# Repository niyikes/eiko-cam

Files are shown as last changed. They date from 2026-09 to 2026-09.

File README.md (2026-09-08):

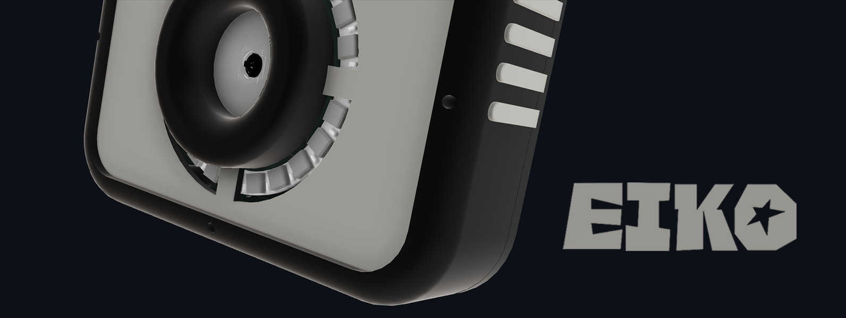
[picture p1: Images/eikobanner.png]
Eiko banner


> *a camera built with the Orange Pi CM4, with rotary encoders, a TFT screen and 24-LED RGB ring.*

---
## What is this?

Eiko is a handheld camera built from scratch, with the Orange Pi CM4.

It takes photos, has a TFT screen and a 24-LED RGB ring around the lens that you can change colors with a rotary encoder.
| | |
|---|---|
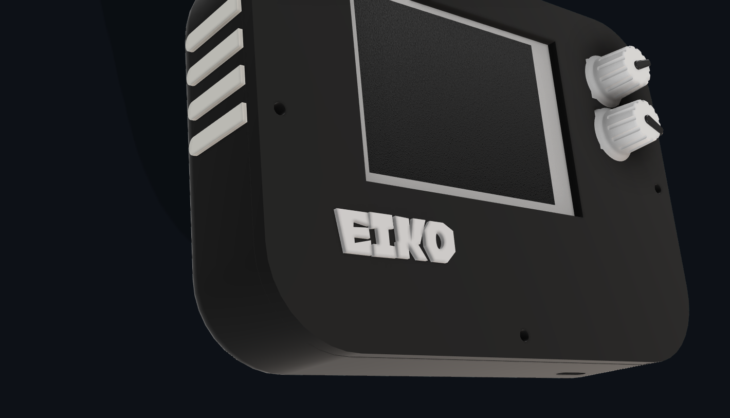
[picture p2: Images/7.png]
Images
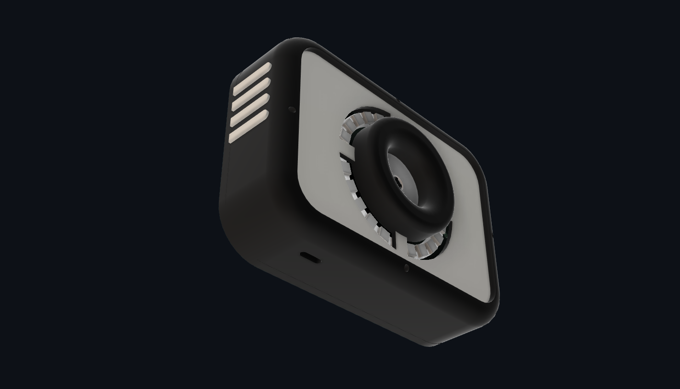
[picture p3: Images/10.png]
Images
||

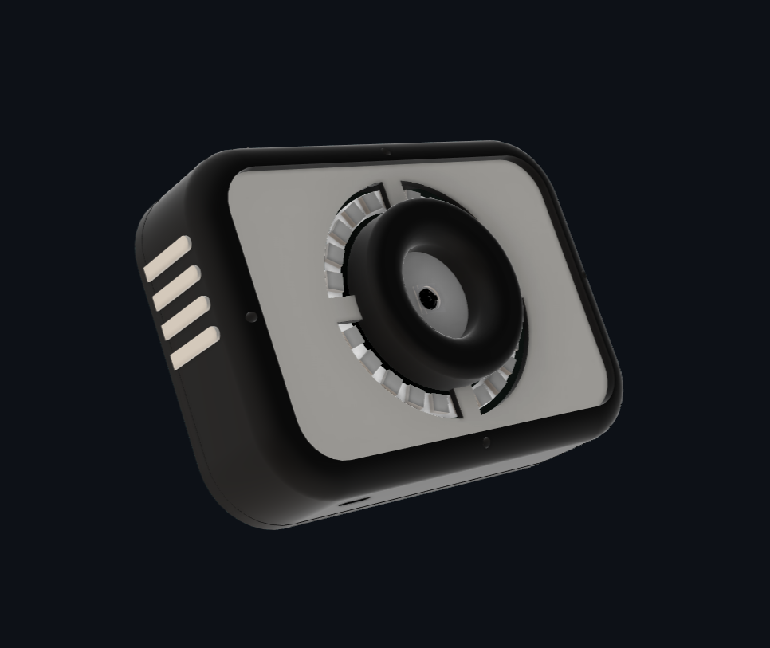
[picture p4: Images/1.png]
case


## features

- live preview on a 2.8" TFT
- full res JPEG capture (using an 8MP IMX219 camera)
- rgb led ring for colorful lighting & flash
- two rotary encoders (one shoots, one controls the leds)
- saves to SD card

## PCB

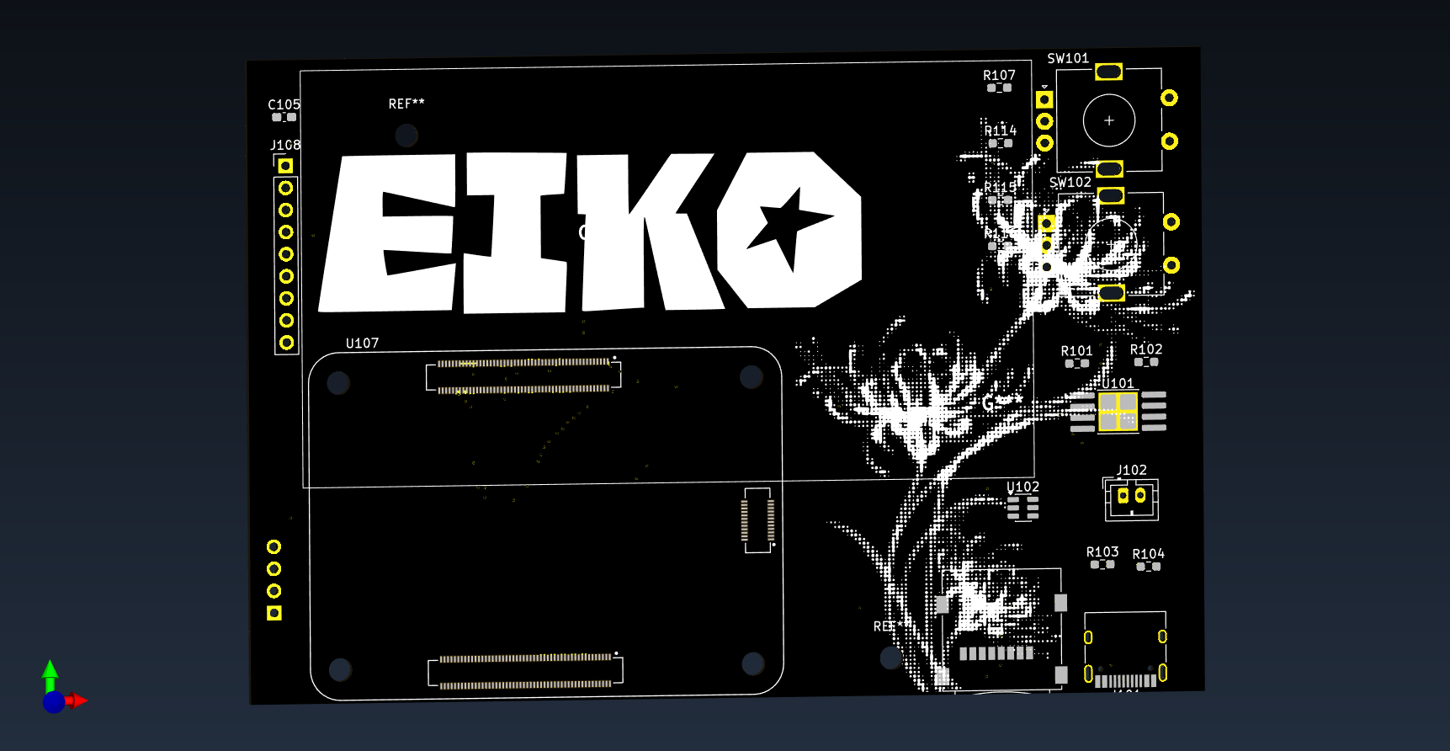
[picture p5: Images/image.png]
front

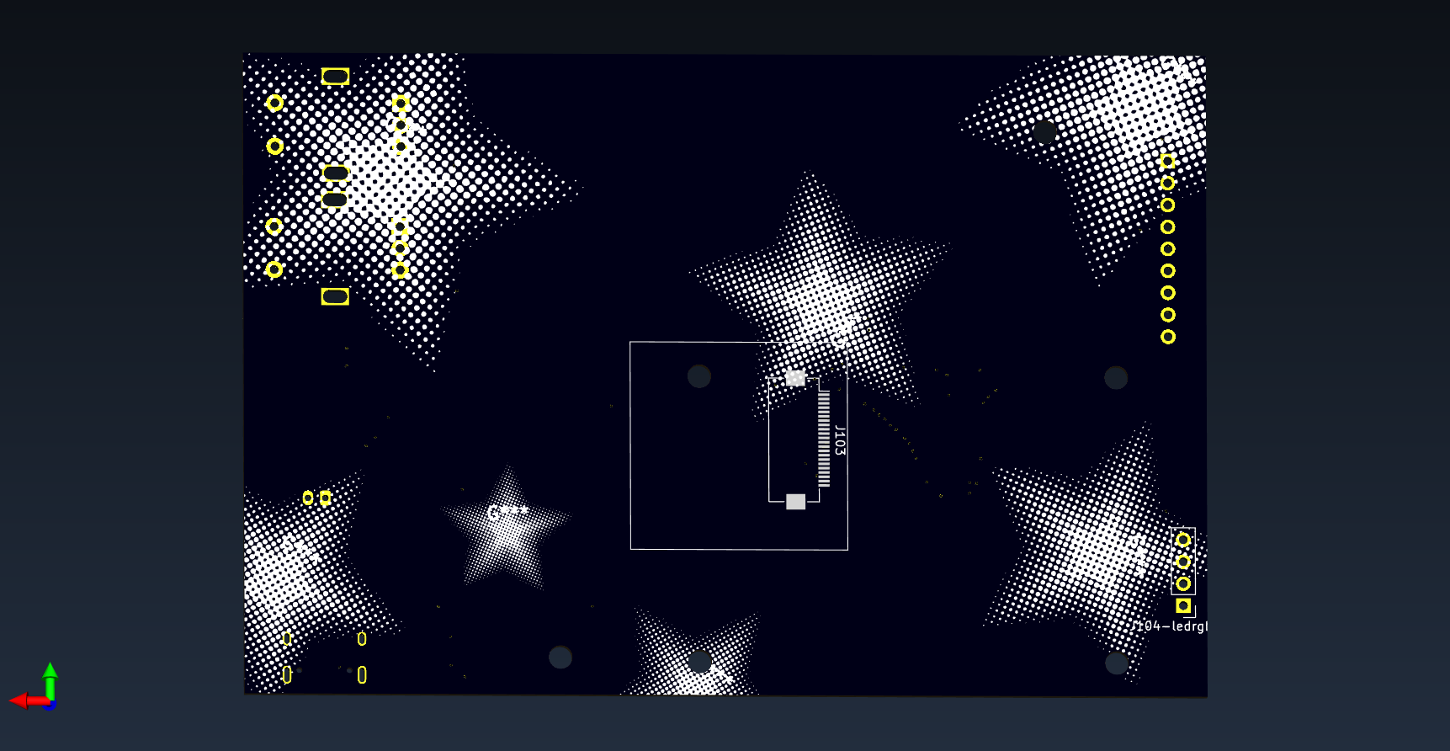
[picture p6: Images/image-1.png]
back


## Cad

| Case Front | Case Back | Plate |
|---|---|---|
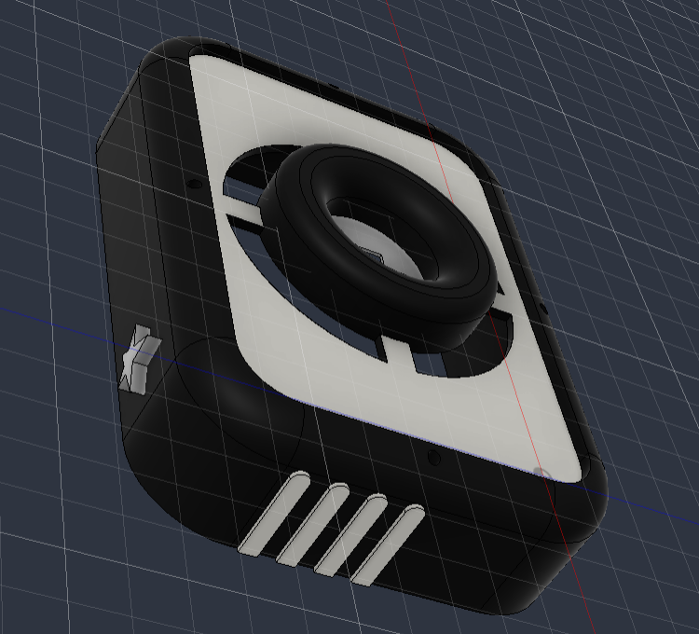
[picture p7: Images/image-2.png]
case front
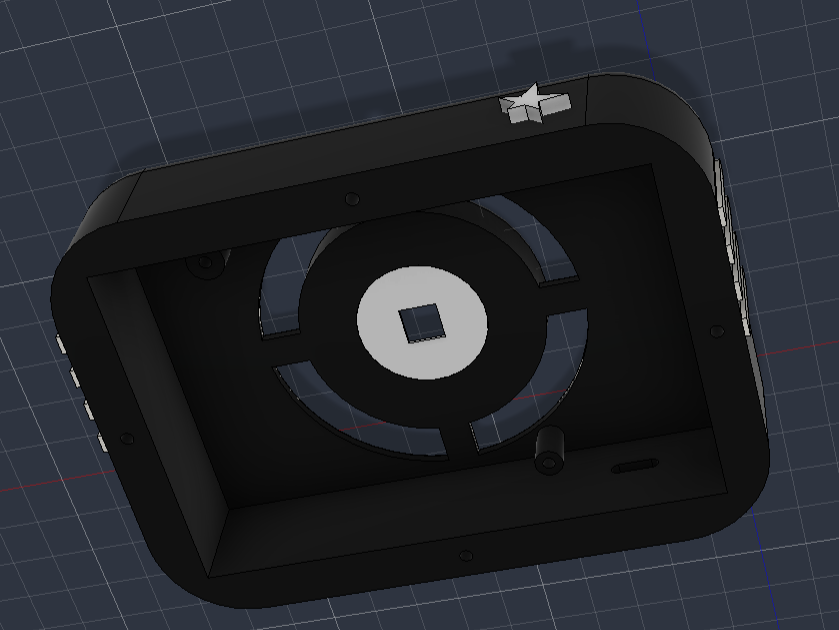
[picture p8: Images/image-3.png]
case back
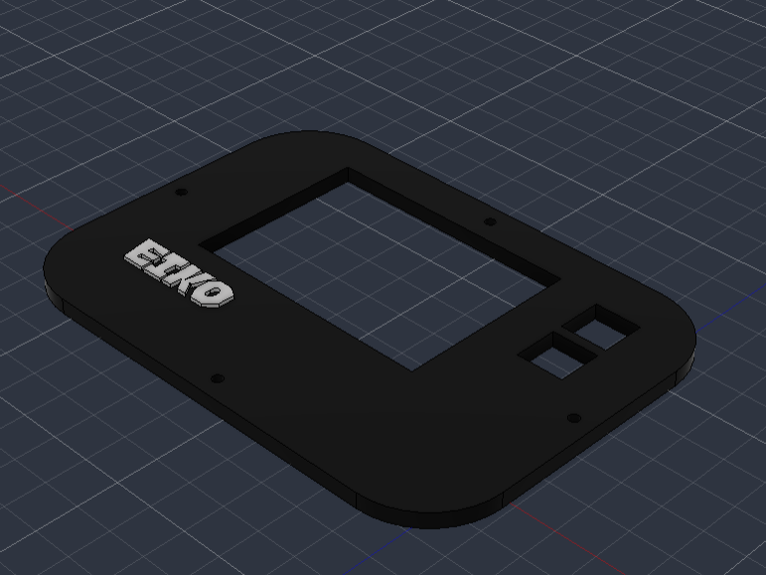
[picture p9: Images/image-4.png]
plate
| | | |

## Firmware
You can find the firmware [here](https://github.com/niyikes/eiko-cam/tree/main/firmware)
| Input | Action |
|---|---|
| Rotate enc1 | Navigate menu |
| Press enc1 | Shutter/Click picture |
| Press enc2 | Toggle LED ring on/off |
| Rotate enc2 | Change LED color |

### Flash the firmware
Connect the Orange Pi CM4 and run:

```
./setup.sh
sudo python3 eiko.py
```

## BOM
| Component | Qty | Price (INR) | Total (INR) | Total (USD) | Source |
|---|-----|---|---|---|---|
| Orange Pi CM4 | 1 | 6095 | 6095 | 64.50 | [crazypi.com](https://www.crazypi.com/Orange-Pi-Compute-Module-4) |
| TP4056 LiPo Charger | 1 | 184 | 184 | 1.95 | [robu.in](https://robu.in/product/tp4056-3-7v-lithium-battery-charging-module-1a-usb-type-c-port-ph2-0-terminal/) |
| USB-C Receptacle | 1 | 280 | 280 | 2.96 | [robu.in](https://robu.in/product/usb4745-03-a-gct-usb-sealed-connector-top-mount-usb-type-c-usb-3-2-receptacle-24-position/) |
| MT3608 Boost Converter | 1 | 20 | 20 | 0.21 | [robu.in](https://robu.in/product/mt3608-xian-aerosemi-tech-boost-type-adjustable-2a-2v24v-sot-23-6-dc-dc-converters-rohs/) |
| MicroSD Storage Board | 1 | 389 | 389 | 4.12 | [robu.in](https://robu.in/product/waveshare-micro-sdtf-storage-board/) |
| Alps EC11E Rotary Encoder | 2 | 415.24 | 830.48 | 8.79 | [element14.com](https://in.element14.com/alps/ec11e15204a3/encoder-vertical-30-det-15ppr/dp/1520804) |
| IMX219 Camera | 1 | 3659 | 3659 | 38.72 | [robu.in](https://robu.in/product/arducam-8mp-imx219-camera-module-with-fisheye-lens-for-jeson-nano-and-raspberry-pi-compute-module/) |
| WS2812 24-LED Ring | 1 | 131 | 131 | 1.39 | [robu.in](https://robu.in/product/24-bit-ws2812-5050-rgb-led-built-full-color-driving-lights-circular-development-board/) |
| 2.8" SPI TFT | 1 | 869 | 869 | 9.20 | [robu.in](https://robu.in/product/2-8-inch-spi-touch-screen-module-tft-interface-240320/) |
| 100nF Cap | 1 | 4.64 | 4.64 | 0.05 | [robu.in](https://robu.in/product/100nf-400v-dip-polyester-film-capacitor-pitch10mm/) |
| 1.2k Resistor | 2 | 1.18 | 2.36 | 0.02 | [sharvielectronics.com](https://sharvielectronics.com/product/1-2k-ohm-1-2-watt-resistor-5-tolerance/) |
| 10k Resistor | 5 | 0.45 | 2.25 | 0.02 | [sharvielectronics.com](https://sharvielectronics.com/product/10k-ohm-1-4-watt-resistor-5-tolerance/) |
| 100k Resistor | 2 | 0.45 | 0.90 | 0.01 | [sharvielectronics.com](https://sharvielectronics.com/product/100k-ohm-1-4-watt-resistor-5-tolerance/) |
| 13k Resistor | 2 | 1.08 | 2.16 | 0.02 | [robu.in](https://robu.in/product/mf25-13k-multicomp-pro-through-hole-resistor-13-kohm-mf25-series-250-mw/) |
| LiPo Battery | 1 | 329 | 329 | 3.48 | [robu.in](https://robu.in/product/nova-103450-2000mah-3-7v-lipo-battery-pack/) |
| M2.5 Screws | 10 | 1.24 | 12.40 | 0.13 | [onlyscrews.in](https://onlyscrews.in/products/m2-5-x-6mm-phillips-pan-head-ss-304-screw) |
| Heat Set Inserts | 10 | 2.50 | 25.00 | 0.26 | [flyrobo.in](https://www.flyrobo.in/m2.5-x-5mm-brass-heat-set-threaded-round-insert-nut) |
| **TOTAL** | | | | **$135.45** | |

I loved making this project, it was super fun and i learnt a LOT in the process. SUPER HAPPY WITH HOW IT TURNED OUT! :D

<br><br>
-ˋˏ✄┈┈┈┈
made with <3 by nia

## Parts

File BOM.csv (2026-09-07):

Name | Qty | Price (INR) | Total (INR) | Total (USD) | Source
Orange Pi CM4 | 1 | 6095 | 6095 | 64.50 | https://www.crazypi.com/Orange-Pi-Compute-Module-4
TP4056 3.7V LiPo Charger | 1 | 184 | 184 | 1.95 | https://robu.in/product/tp4056-3-7v-lithium-battery-charging-module-1a-usb-type-c-port-ph2-0-terminal/
USB-C receptacle | 1 | 280 | 280 | 2.96 | https://robu.in/product/usb4745-03-a-gct-usb-sealed-connector-top-mount-usb-type-c-usb-3-2-receptacle-24-position/
MT3608 boost converter | 1 | 20 | 20 | 0.21 | https://robu.in/product/mt3608-xian-aerosemi-tech-boost-type-adjustable-2a-2v24v-sot-23-6-dc-dc-converters-rohs/
Micro SD(TF) Storage Board | 1 | 389 | 389 | 4.12 | https://robu.in/product/waveshare-micro-sdtf-storage-board/
Alps EC11E Rotary Encoder | 2 | 415.24 | 830.48 | 8.79 | https://in.element14.com/alps/ec11e15204a3/encoder-vertical-30-det-15ppr/dp/1520804
IMX219 camera | 1 | 3659 | 3659 | 38.72 | https://robu.in/product/arducam-8mp-imx219-camera-module-with-fisheye-lens-for-jeson-nano-and-raspberry-pi-compute-module/
LED Ring | 1 | 131 | 131 | 1.39 | https://robu.in/product/24-bit-ws2812-5050-rgb-led-built-full-color-driving-lights-circular-development-board/
SPI TFT 2.8" | 1 | 869 | 869 | 9.20 | https://robu.in/product/2-8-inch-spi-touch-screen-module-tft-interface-240320/
100nF Cap | 1 | 4.64 | 4.64 | 0.05 | https://robu.in/product/100nf-400v-dip-polyester-film-capacitor-pitch10mm/
1.2k Resistor | 2 | 1.18 | 2.36 | 0.02 | https://sharvielectronics.com/product/1-2k-ohm-1-2-watt-resistor-5-tolerance/
10k resistor | 5 | 0.45 | 2.25 | 0.02 | https://sharvielectronics.com/product/10k-ohm-1-4-watt-resistor-5-tolerance/
100k resistor | 2 | 0.45 | 0.9 | 0.01 | https://sharvielectronics.com/product/100k-ohm-1-4-watt-resistor-5-tolerance/
13k resistor | 2 | 1.08 | 2.16 | 0.02 | https://robu.in/product/mf25-13k-multicomp-pro-through-hole-resistor-13-kohm-mf25-series-250-mw-%25c2%25b1-1-axial-leaded-250-v/
LiPo battery | 1 | 329 | 329 | 3.48 | https://robu.in/product/nova-103450-2000mah-3-7v-lipo-battery-pack/
M2.5 screws | 10 | 1.24 | 12.4 | 0.13 | https://onlyscrews.in/products/m2-5-x-6mm-phillips-pan-head-ss-304-screw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
Heat set inserts | 10 | 2.5 | 25 | 0.26 | https://www.flyrobo.in/m2.5-x-5mm-brass-heat-set-threaded-round-insert-nut?tracking=ads
 |  |  | TOTAL (USD): | 135.45

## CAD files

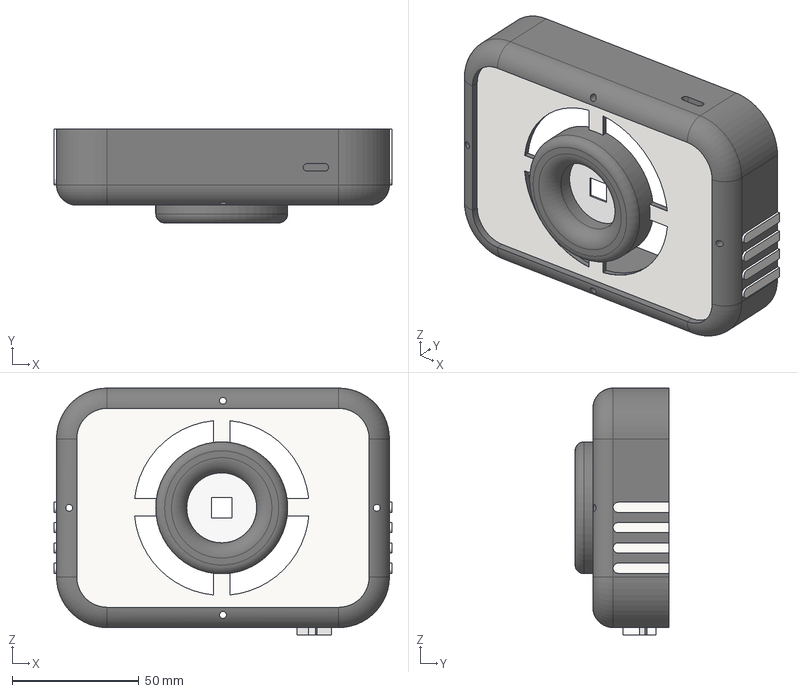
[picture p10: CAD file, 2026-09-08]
CAD/eiko-cam body.step
133.2 x 37.0 x 97.3 mm

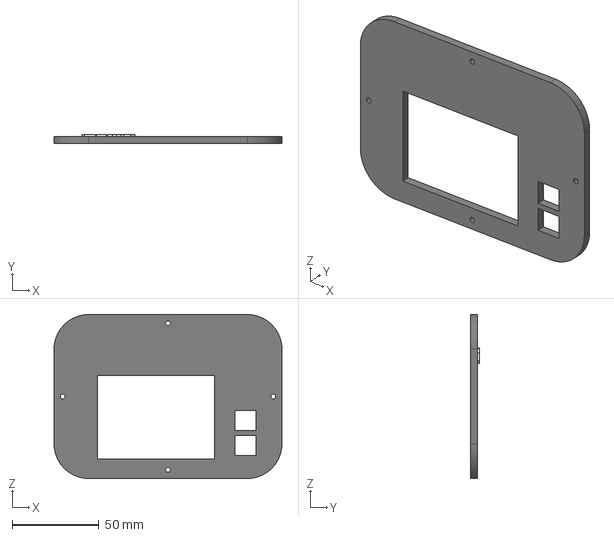
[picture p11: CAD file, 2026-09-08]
CAD/top plate.step
131.2 x 5.00 x 94.4 mm

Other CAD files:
CAD/eiko-assembly.f3z
CAD/eiko-cam body.f3d
CAD/top plate.f3d

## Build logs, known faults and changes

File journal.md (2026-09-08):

---
title: "EikoCam"
author: "Nia (niyikes)"
description: "A camera built around the Orange Pi CM4 with a tft and an LED ring"
created_at: "21-06-2026"
---

### Total hours (excluding journal and firmware time) = 14h 39m 

<br>

# Day 1: Starting with schematics!

I want to build a wiggly cam (quad cameras inspired by k4mera).

I have made some PCBs before but nothing this complex, so it was a huge learning experience for me. 

[I FORGOT TO LAPSE THE FIRST 30 MINS AAAA]

For day 1, I roughed out the schematics:
* 4 camera connectors (cam1-cam4)
* the Raspi CM4 module
* power section (USB-C + TP4056 charger + MT3608 boost converter)
* RGB LED flash section
* rotary encoders (2)
* an SD card slot

excluse the low qual
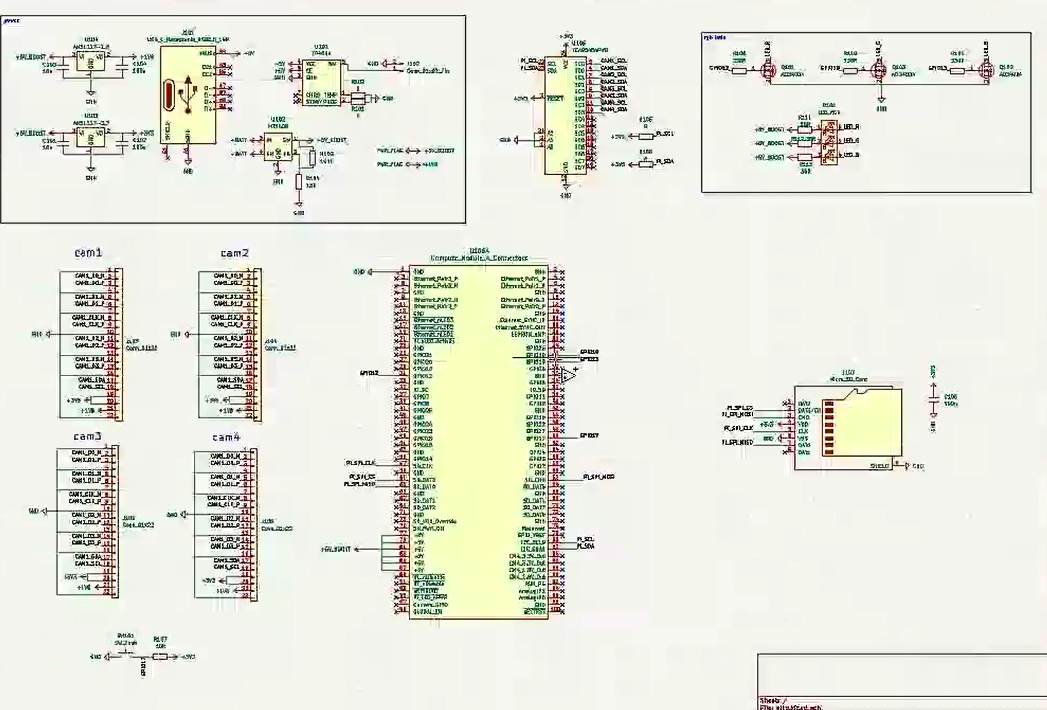
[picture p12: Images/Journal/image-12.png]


[lapse](https://lapse.hackclub.com/timelapse/ubU5O429R0UL)

**Total time tracked: 1h4m**

# Day 2: finishing up schematics & ERC 
SO day 2 was just me fixing the billion erc errors i got

then, I worked on the CSI camera lanes on the CM4 module like it was kinda confusing trying to figure out where to put what.

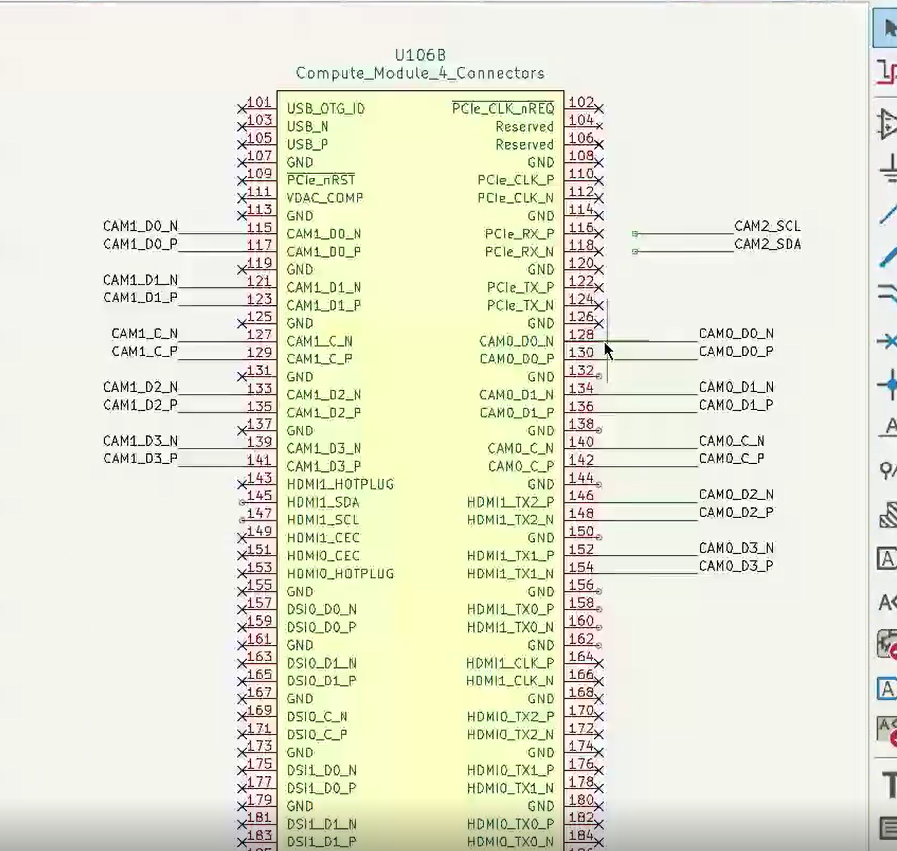
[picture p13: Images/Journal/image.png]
cm4


IDK WHY IT TOOK 40 MINS i think im kinda dumb

(please spare me its FOUR CAMERAS im scared)

[Lapse](https://lapse.hackclub.com/timelapse/0ZSWGH-R307w)
**Total time tracked: 41m**

# Day 3: switching to the Orange Pi CM4
I realised the RPi CM4 is not available in my country to buy + its VERY expensive. I tried finding the cheapest alternative, and i settled for the Orange Pi CM4.

I spent the session googling the pinout and figuring out how its different from RPi CM4. AND trying to find the symbols/footprints for it.

its kinda similar but some signals are in different places and the naming is also kinda different. 

[Lapse](https://lapse.hackclub.com/timelapse/Rts7u5A0DIab)
**Total time tracked: 23m**

# Day 4: ERC + Footprints

Fixing ERC errors and assigning footprints.

UHHH so idk IT WAS PRETTY MUNDANE; mostly just me talking to ai about the erc errors

then  i googled the footprints and downloaded them and stuff, which was really boring/easy but time consuming

SCHEMATICS ARE DONE!!!! PCB layout time (the scary part :fear:)

[Lapse](https://lapse.hackclub.com/timelapse/uZAfYT_P7OIX)
**Total time tracked: 23m**

# Day 5: PCB TIME

I started by fixing up the schematics a bit, i messed up the schematics a bit last time
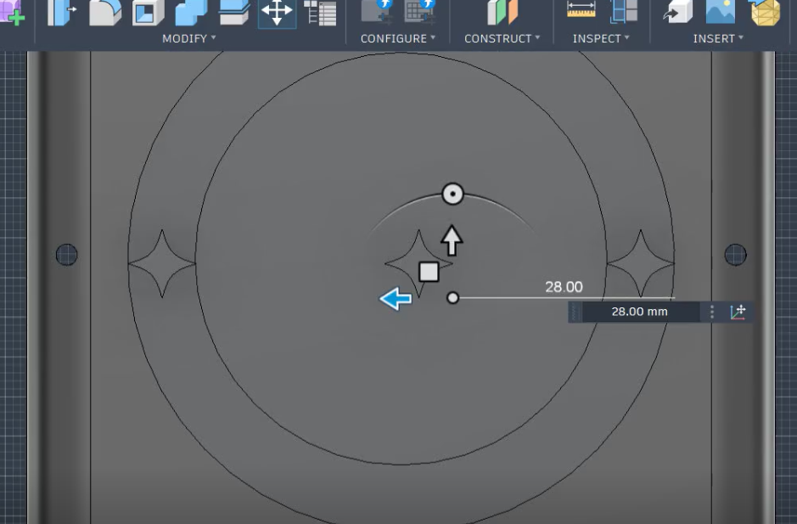
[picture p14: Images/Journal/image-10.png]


THEN WE GET TO THE PCB LAYOUT!
I spent a good portion of my time googling the dimensions of some of my components (AGAIN, IM NEW TO HARDWARE; NOT SURE IF THIS IS THE RIGHT WAY TO DO IT)

I tried laying them out and doing some uhhh maths??? (idk what im doing)

I KINDA ragequit along the way, I got a bit frustrated lol

The four cameras were kinda hard to figure out. It got too complex sob

[Lapse](https://lapse.hackclub.com/timelapse/Aepzxww6glKQ)
**Total time tracked: 45m**

# Day 6: RESEARCHING PARTS

UHHHH HI JOURNAL!!

i got rid of the 4 camera thingies. I got bored/frustrated/annoyed at the eiiiiko idea + IT WAS EXPENSIVE AS HELL. i renamed it to eiko-cam.

I spent most of my time researching on parts and stuff, so that i can get an idea of the size (for the pcb)
By the end of this, i had a rough idea of the layout
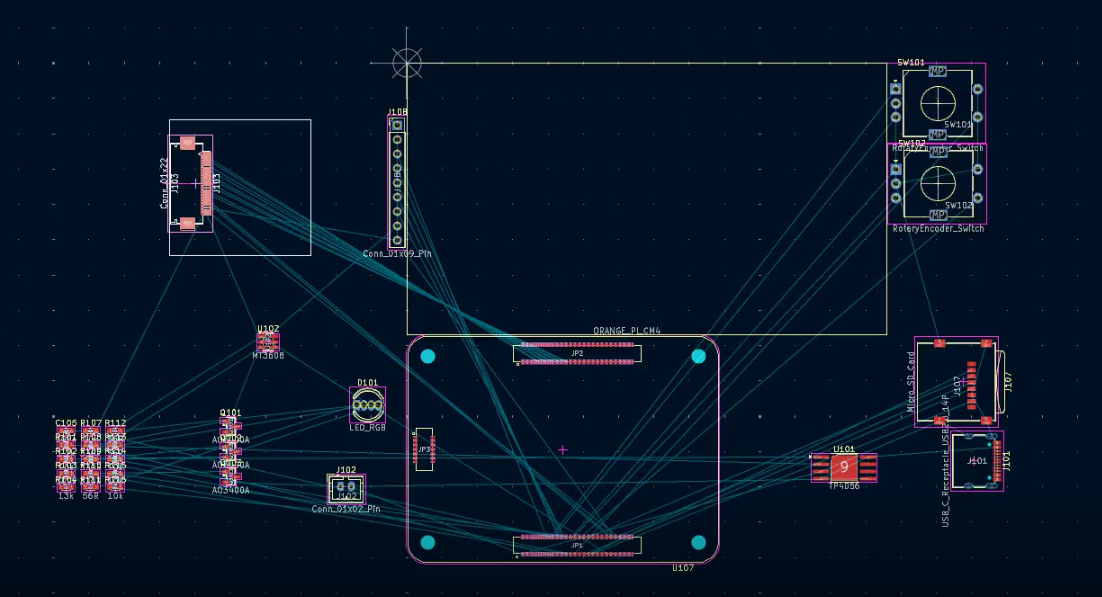
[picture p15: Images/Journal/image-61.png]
layout


[Lapse](https://lapse.hackclub.com/timelapse/T8M4nXyhyFp5)
**Total time tracked: 49m**

# Day 7: LED RING -- schematics + PCB!

So, since i got rid of the 4 camera system, the entire project was looking really lame, i lost motivation to finish this project.
At this point i thought a normal ass camera was too boring; i needed a cool gimmick.

I decided to add a 24bit led ring to it, so we can click cool pictures WITH led? how cool is that? very cool! (thank u journal ily)

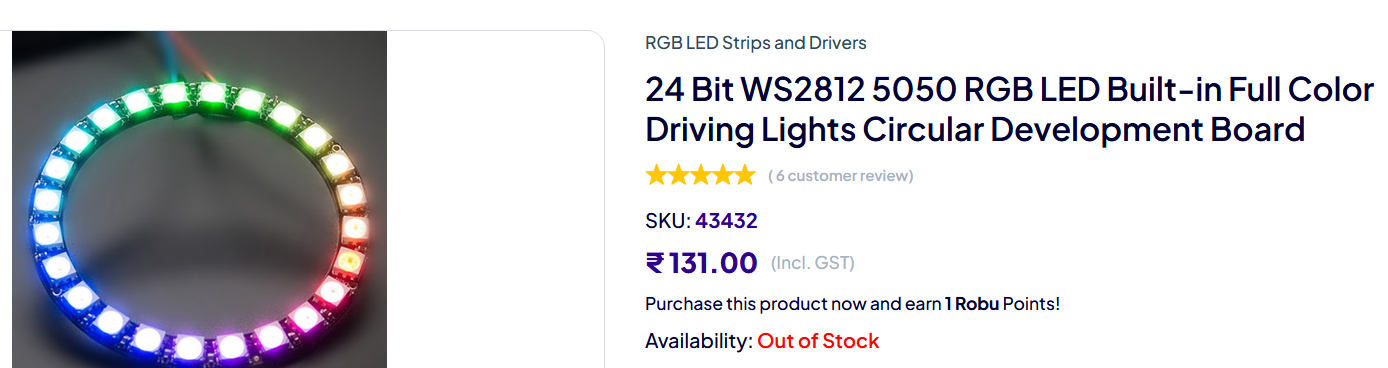
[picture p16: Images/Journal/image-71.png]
ring


I fixed up the schematics a bit first, then i got to laying it on the pcb out ALL OVER AGAIN AAAAAAa

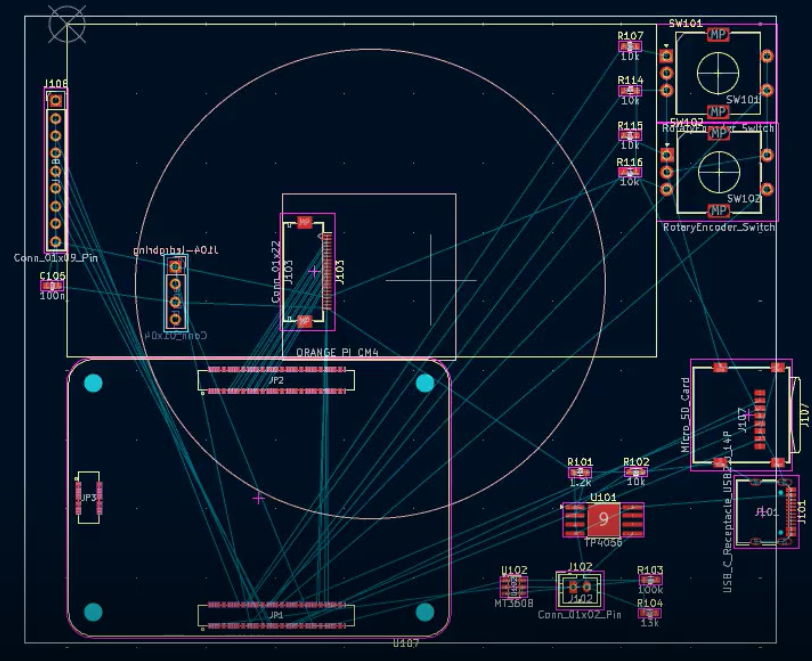
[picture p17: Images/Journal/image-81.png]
pcb


AT THIS POINT, i was mostly done with the pcb, now for the fun part!!! (routing traces yayyyyyyyyyy)

[Lapse](https://lapse.hackclub.com/timelapse/4bgr98WrAynd)
**Total time tracked: 1h2m**

# Day 8: ROUTING TRACES
i love routing traces. very therapeutic. very fun. i love routing traces. did i mention i love routing traces? because i love routing traces.
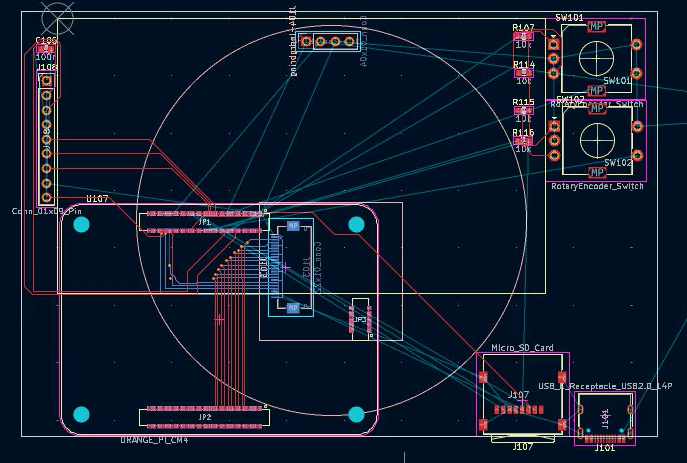
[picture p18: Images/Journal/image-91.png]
mostly routed


so basically i routed traces and yeah thats what i did.

[Lapse](https://lapse.hackclub.com/timelapse/dpy_0H8_tGBq)
**Total time tracked: 38m**

# Day 9: ROUTING (more) TRACES
HI JOURNAL I ROUTED TRACES TODAY!?!?!?!

the ever-humble design rules checker:

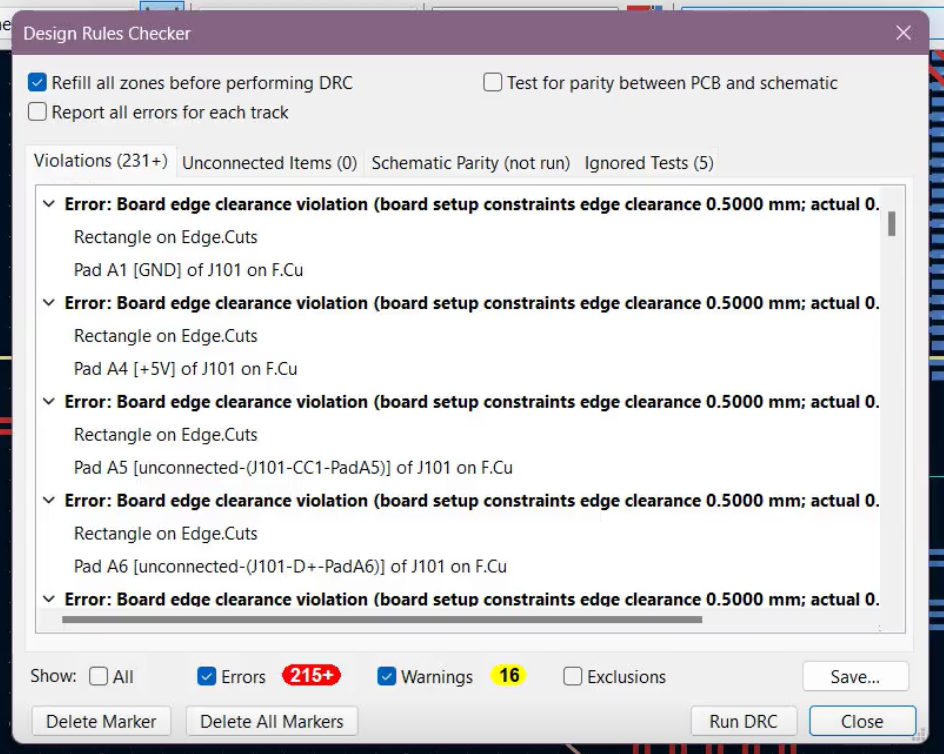
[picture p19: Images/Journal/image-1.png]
drc errors


eh ill fix it tmrw
[Lapse](https://lapse.hackclub.com/timelapse/dNWne6YC-ZzR)
**Total time tracked: 47m**

# Day 10: fixing drc errors (sob), starting CAD
so the main error was "Front solder mask aperture bridges items with different nets".

reddit thread
i trusted this friendly redditor from 2years ago, and reduced the soldermask expansion.

that did the trick and removed most errors. 

0 errors

seeing 0 errors is SO satisfying.

then i looked up step files for my components so i can make my pcb, which would help me with cad.
AAAAAAAAAAAAA CAD I DONT WANNA DO CAD IM SO BAD AT CAD IM DREADING IT SO  MUCH

[Lapse](https://lapse.hackclub.com/timelapse/_rPDu_U728Vh)

**Total time tracked: 1h3m**

# Day 11: CAD AAAAAA HELP
i started with cad, just so you know, I SUCK AT CAD. i was dreading this all along. im SO scared of cad. 

anyway, while making this i just kinda did whatever, i made a box and kindaaa followed hackpad tutorial.

I couldve made it way smaller, yes, but i wanted it to have a boxy and big-ish design so its satisfying to hold. 

I wanted the main hole to be shaped like a sun, so i tried to find a sun dxf but it was REALLY bad, i tried fixing it, but i eventually gave up

then, i made something KINDA cool looking at the end BUT i didnt account for the rgb ring, so i have to redo it tmrw.

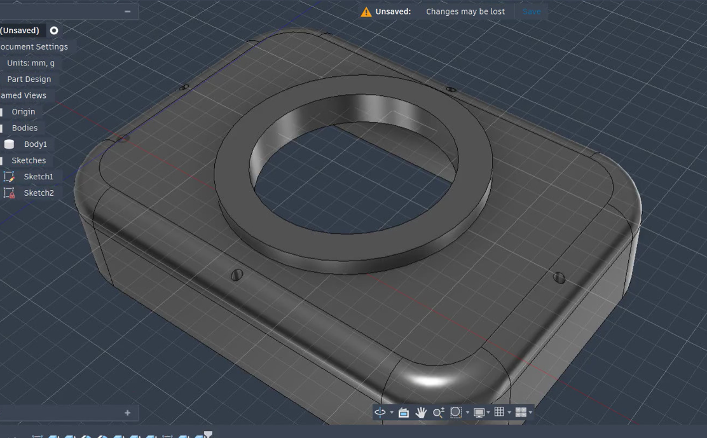
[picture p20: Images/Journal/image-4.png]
cam cad


[Lapse](https://lapse.hackclub.com/timelapse/8Qk8iL_9YuwQ)
**Total time tracked: 1h1m**

# Day 12: CAD AAAAAA HELP
I wanted the rgb ring to have some sort of cool pattern instead of regular holes, so i decided to make the holes star shaped

unfortunately im a chud and horrible at cad, so i couldnt figure out how to resize the star to exact dimensions.

i looked it up and figured it out, but NOW i didnt know how to move the imported svg sketch

SO, I MADE THE STAR A BODY THAT I COULD MOVE AROUND
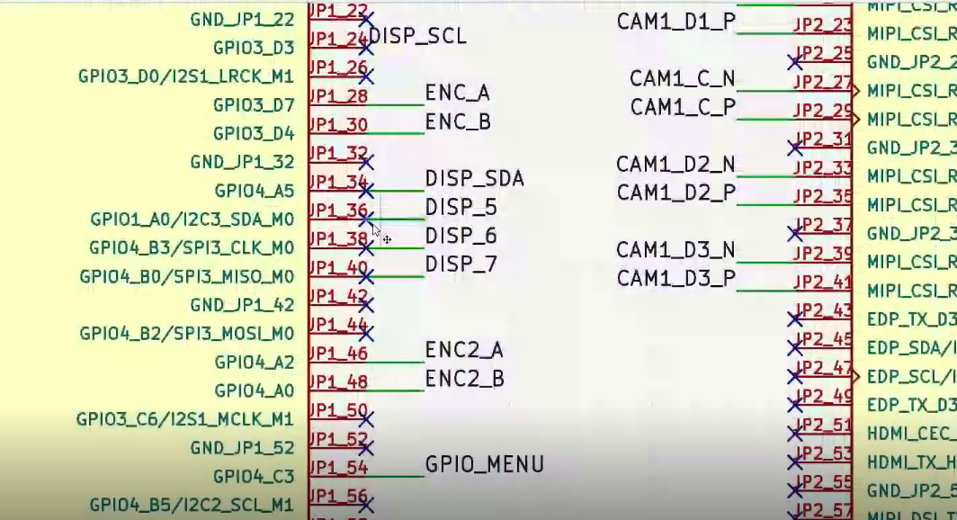
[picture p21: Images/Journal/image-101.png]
dumbass star


am i smart or am i a dumb idiot
pls dont answer that im embarrassed

[Lapse](https://lapse.hackclub.com/timelapse/ZWWJTxKr0Vqp)
**Total time tracked: 1h5m**

# Day 13: when will the suffering end (cad)
so i finished making the holes for the rgb, NO CLUE if its gna work, but i did it and thats all that matters :>

i have to put in more holes after, i only put 4 so far, but thats something ill figure out tomorrow (hopefully)
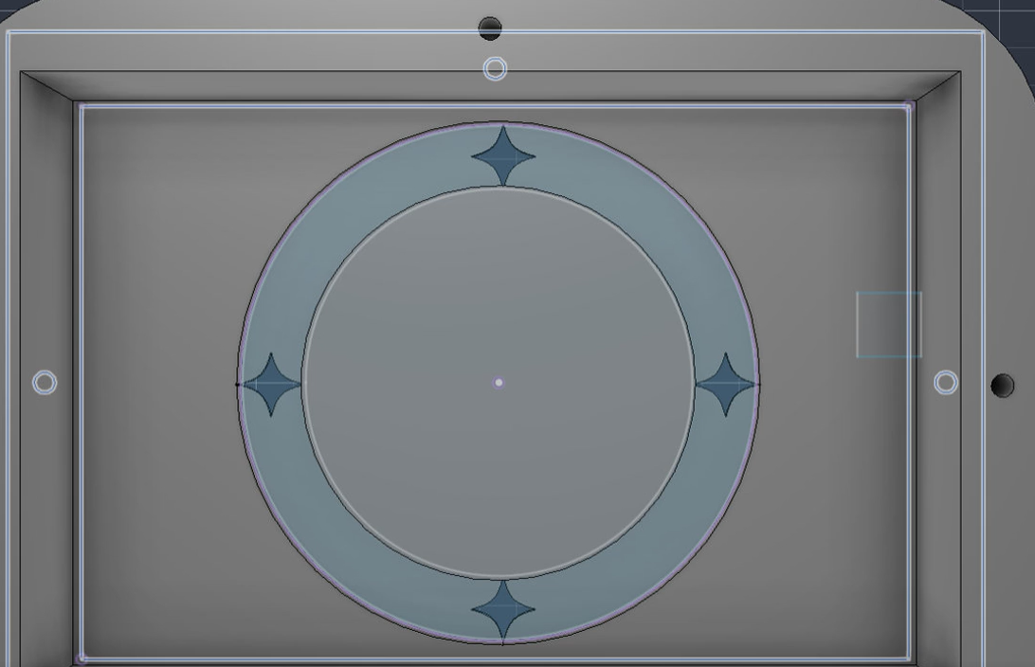
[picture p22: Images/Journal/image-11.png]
star hole


i tried making the top plate, and making an assembly to see if everything fits together

[Lapse](https://lapse.hackclub.com/timelapse/bmARxUfmpesB)
**Total time tracked: 25m**

# Day 14: most embarrassing cad sesh of all time
so im coming back to this proj after a LONG time. anyway, i just want to finish this proj asap cuz i have exams & sunbeam coming up and i need to get my stipeds before the deadline

i tried to do something different, I HAVE NO CLUE if it is practical, i think it is BUT IT LOOKS KINDA BAD

so i initially tried to put circles + stars to hold the circle hole thingy together
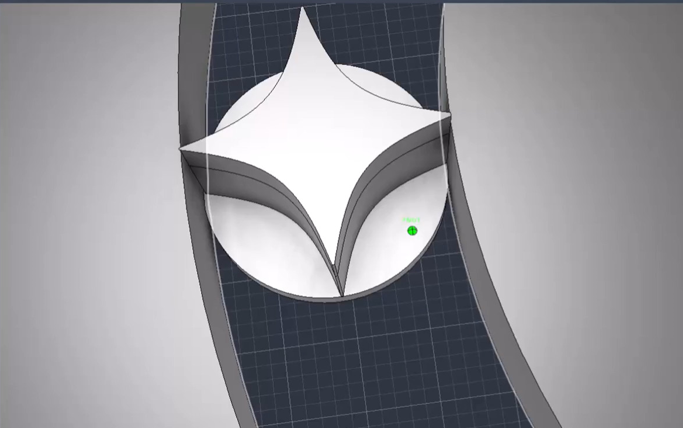
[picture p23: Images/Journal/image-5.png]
starsandcircles

and i wasnt sure if it was practical, so i changed it to rectangles
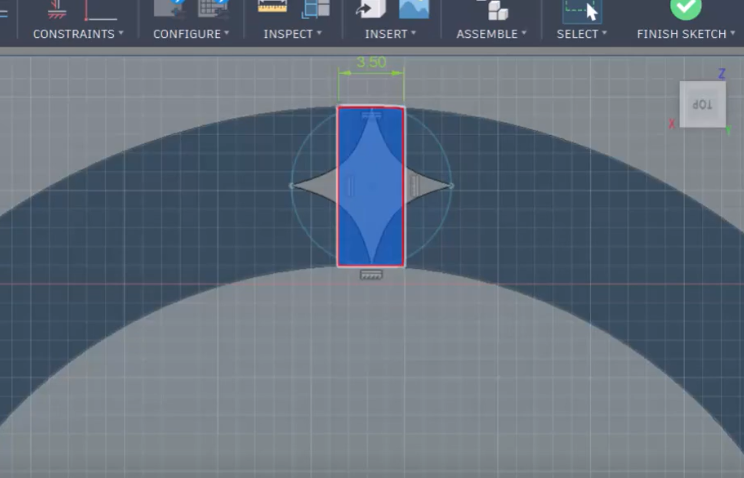
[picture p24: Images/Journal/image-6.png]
rect and star

then i wasnt sure if THIS was practical either, so i changed the entire thing to just rectangle, it looks ugly in cad, but i think itll look fine irl
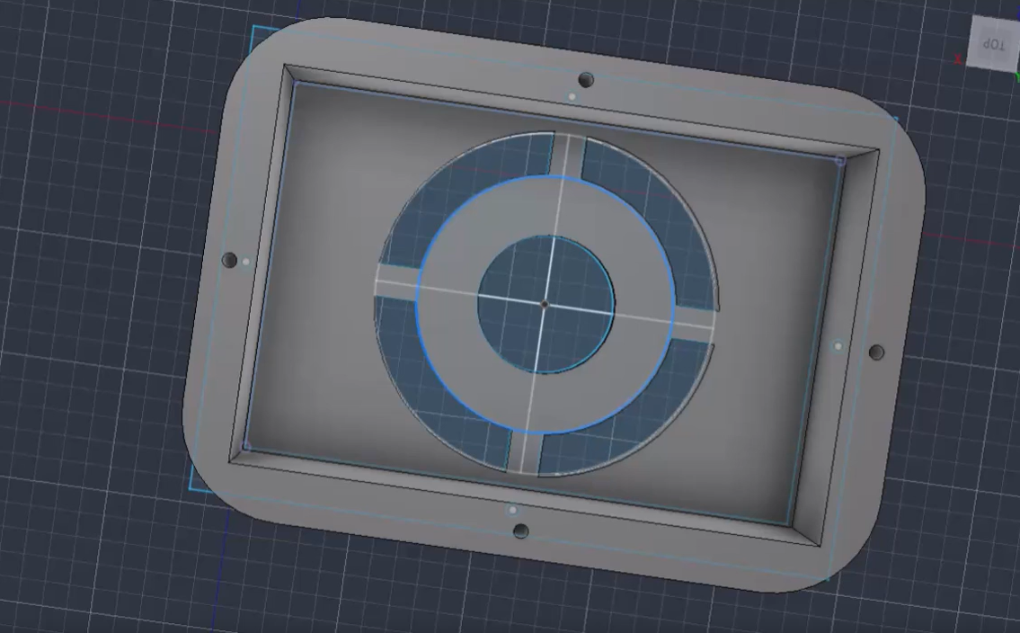
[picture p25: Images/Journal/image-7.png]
uhhh cam cad


then i started with the top plate, but ragequit like i always do waaa :0

PS: Lapse bugged and saved this project to the wrong hackatime Project!!!!!! 
[Lapse](https://lapse.hackclub.com/timelapse/Y-OtEQbrefqc)

**Total time tracked: 1h25m**

# Day 15: DONE WITH CAD!!!!
I finished the top plate! 
For the main body, i tried making it a bit better looking, it still looks weirddddd but its alright i guess. I tried making an angled extrusion but i couldnt figure out how that worked

For the top plate, i tried to find a cool font for branding, that took a while and finally decided to make a logo thing for eiko myself on figma. I exported that as an svg and YAY

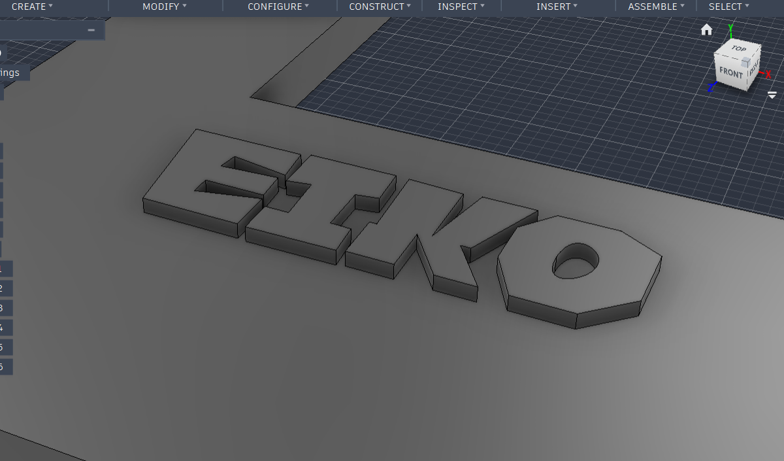
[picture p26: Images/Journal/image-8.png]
eiko logo


THEN I finished the BOM, (its on lapse as eiko [16]) which surprisingly didnt take that long.

[Lapse 1](https://lapse.hackclub.com/timelapse/XWttw3xPp7c_)
[Lapse 2](https://lapse.hackclub.com/timelapse/xnEHjDXaLeAr)
**Total time tracked: 51m + 33m = 1h44m**

# Day 17: Finishing touches, assembly and renders
It took SO LONG trying to render everything AND make it look good. it still doesnt look good. im not proud of it. I completely changed the color scheme which i MIGHT regret when i get up. ok i think i regret it already. 

update: while writing this journal, i changed the colors to dark gray and white and it looks SO much cuter, im keeping this. (it took 30 mins and i didnt lapse it cuz i thought itd take 2 mins)

i think im super proud abt how it turned out now :3

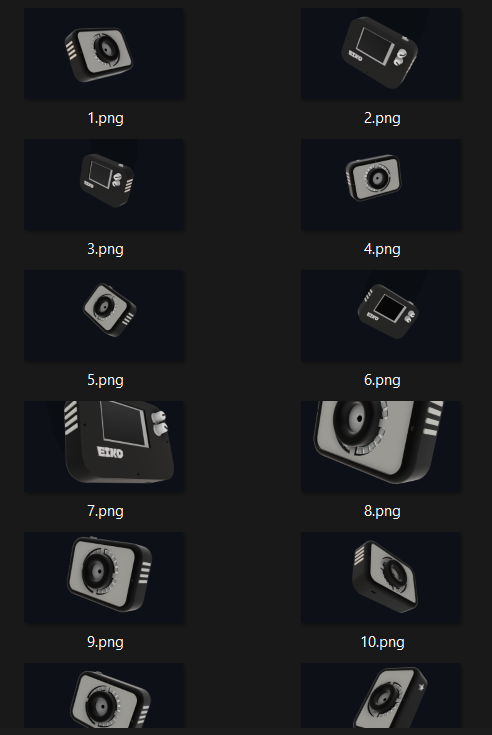
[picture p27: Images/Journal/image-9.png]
renders


now i only have firmware left, which ill make super basic for now, and im DONE!!!! YAYAYAYAYAYY

im super exhausted rn, its 4:50am and its a school day AND i have a physics and math exam like SOON

[Lapse](https://lapse.hackclub.com/timelapse/6tRoa_z47z9U)
**Total time tracked: 1h24m**

thank you reviewer, thank you horizons, thank you hack club <3

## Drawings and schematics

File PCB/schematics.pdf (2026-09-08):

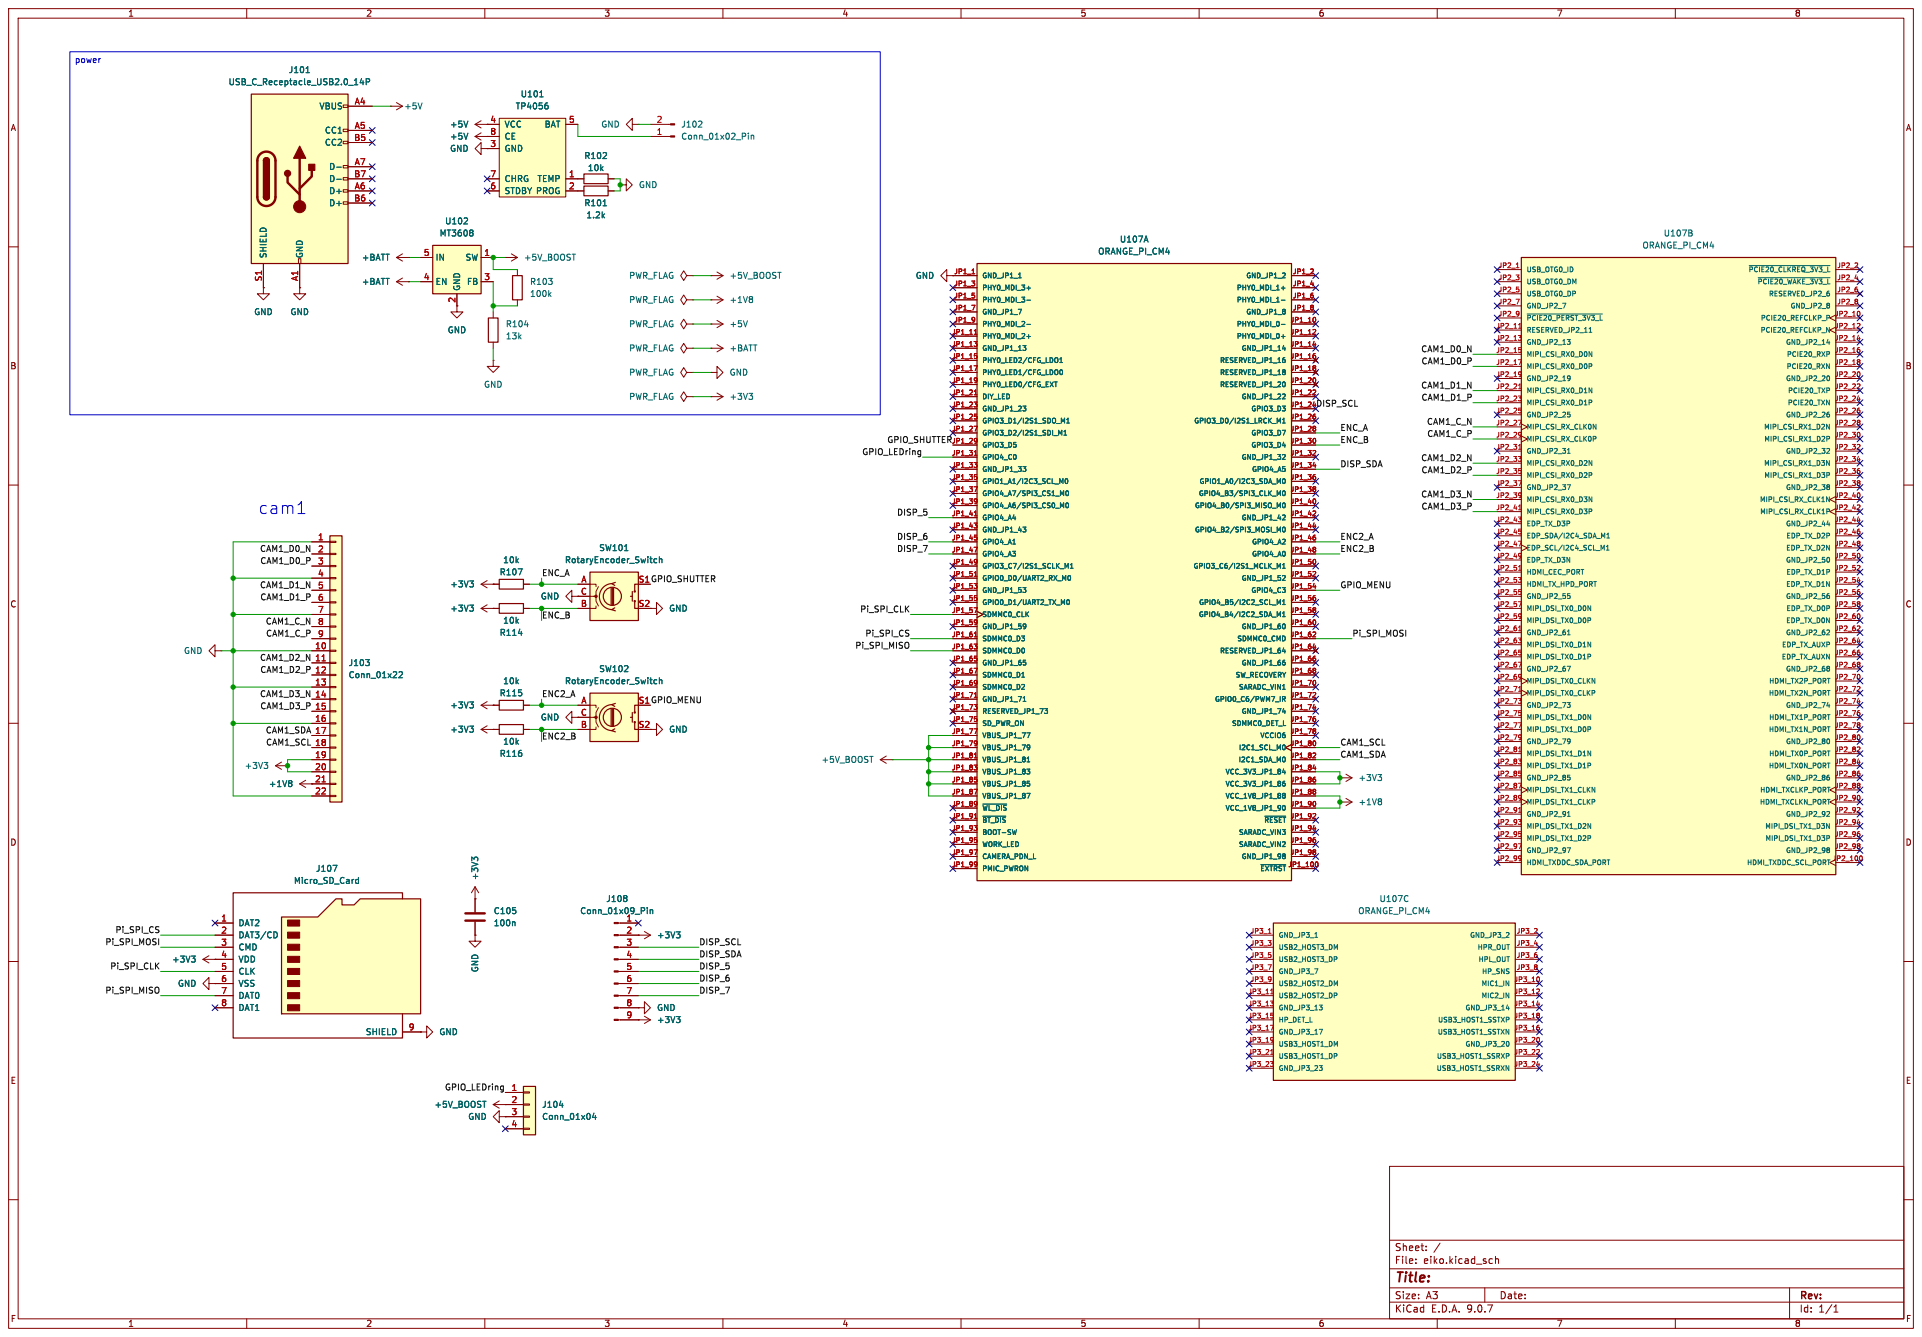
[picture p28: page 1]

2 SW 1 FB 3 U102 MT3608 GNDSHIELD S1 GND A1 VBUS A4 CC1 A5 CC2 B5 D- A7 D- B7 D+ A6 D+ B6

Id: 1/1 Title: File: eiko.kicad_sch Sheet: /

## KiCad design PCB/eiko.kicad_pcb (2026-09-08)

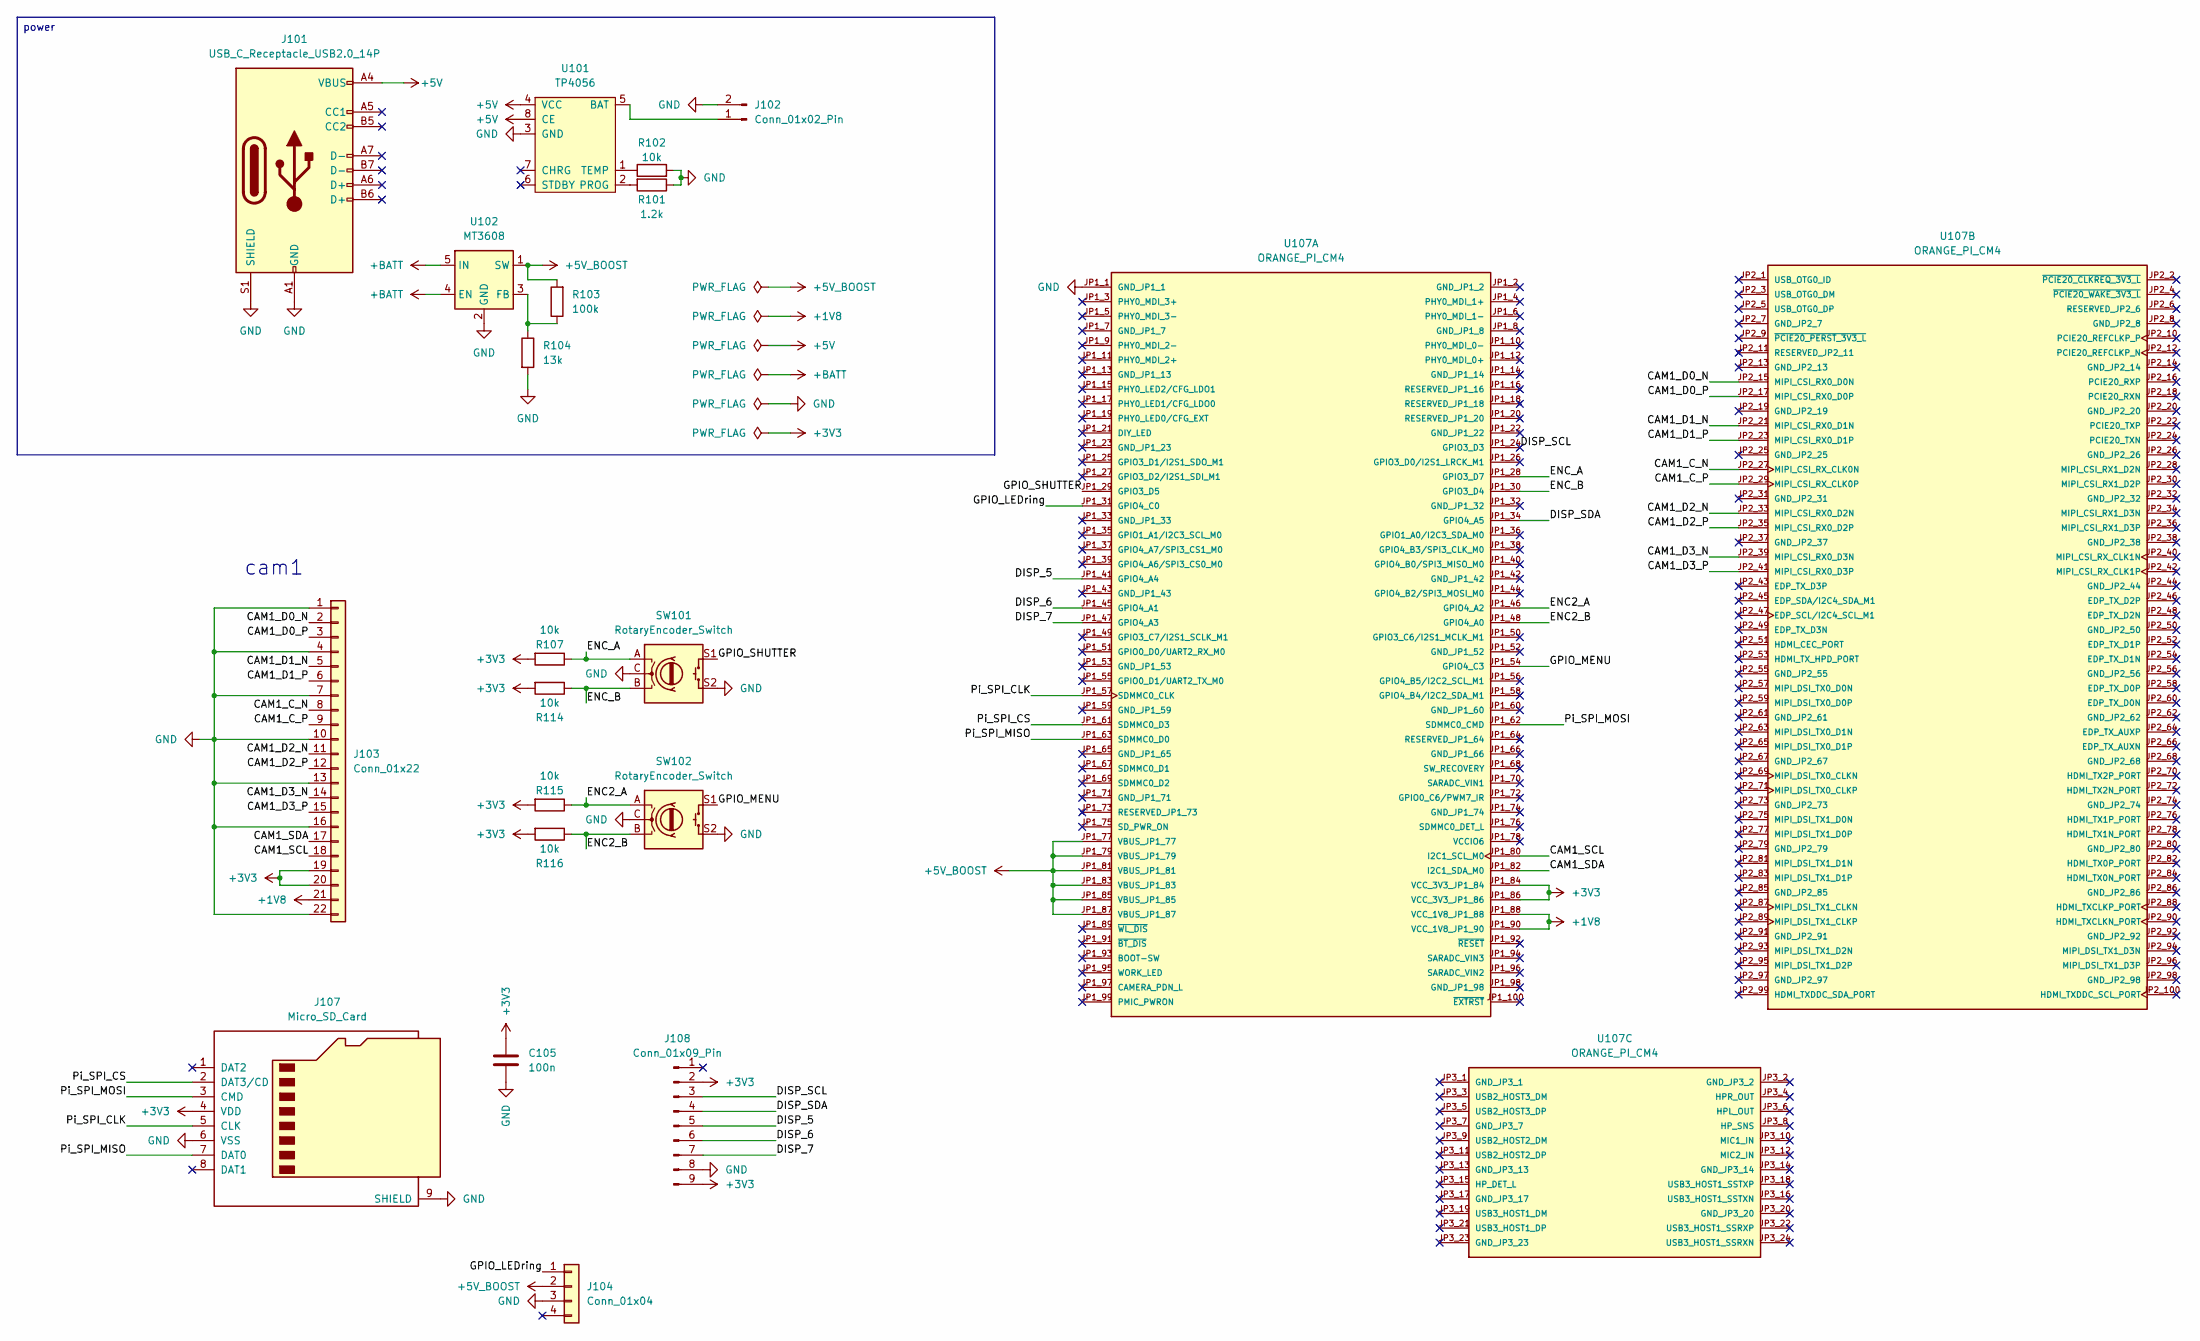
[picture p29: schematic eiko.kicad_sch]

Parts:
C105: 100n; C_0603_1608Metric_Pad1.08x0.95mm_HandSolder
J101: USB_C_Receptacle_USB2.0_14P; USB_C_Receptacle_HRO_TYPE-C-31-M-12
J102: Conn_01x02_Pin; JST_PH_B2B-PH-K_1x02_P2.00mm_Vertical
J103: Conn_01x22; Hirose_FH12-22S-0.5SH_1x22-1MP_P0.50mm_Horizontal
J104: Conn_01x04; PinHeader_1x04_P2.54mm_Vertical
J107: Micro_SD_Card; microSD_HC_Wuerth_693072010801
J108: Conn_01x09_Pin; PinHeader_1x09_P2.54mm_Vertical
R101: 1.2k; R_0603_1608Metric_Pad0.98x0.95mm_HandSolder
R102, R107, R114, R115, R116: 10k; R_0603_1608Metric_Pad0.98x0.95mm_HandSolder
R103: 100k; R_0603_1608Metric_Pad0.98x0.95mm_HandSolder
R104: 13k; R_0603_1608Metric_Pad0.98x0.95mm_HandSolder
SW101, SW102: RotaryEncoder_Switch; RotaryEncoder_Alps_EC11E-Switch_Vertical_H20mm
U101: TP4056; SOP-8-1EP_4.57x4.57mm_P1.27mm_EP4.57x4.45mm; LCSC C16581
U102: MT3608; SOT-23-6
U107: ORANGE_PI_CM4; MODULE_ORANGE_PI_CM4; PARTREV v1.2

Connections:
+1V8: J103.21, U107.JP1_88 (VCC_1V8_JP1_88), U107.JP1_90 (VCC_1V8_JP1_90)
+3V3: C105.1, J103.19, J103.20, J107.4 (VDD), J108.2, J108.9, R107.2, R114.2, R115.2, R116.2, U107.JP1_84 (VCC_3V3_JP1_84), U107.JP1_86 (VCC_3V3_JP1_86)
+5V: J101.A4 (VBUS), J101.A9 (VBUS), J101.B4 (VBUS), J101.B9 (VBUS), U101.4 (VCC), U101.8 (CE)
+5V_BOOST: J104.2, R103.2, U102.1 (SW), U107.JP1_77 (VBUS_JP1_77), U107.JP1_79 (VBUS_JP1_79), U107.JP1_81 (VBUS_JP1_81), U107.JP1_83 (VBUS_JP1_83), U107.JP1_85 (VBUS_JP1_85), U107.JP1_87 (VBUS_JP1_87); also elsewhere on the board
+BATT: U102.4 (EN), U102.5 (IN)
/CAM1_C_N: J103.8, U107.JP2_27 (MIPI_CSI_RX_CLK0N)
/CAM1_C_P: J103.9, U107.JP2_29 (MIPI_CSI_RX_CLK0P)
/CAM1_D0_N: J103.2, U107.JP2_15 (MIPI_CSI_RX0_D0N)
/CAM1_D0_P: J103.3, U107.JP2_17 (MIPI_CSI_RX0_D0P)
/CAM1_D1_N: J103.5, U107.JP2_21 (MIPI_CSI_RX0_D1N)
/CAM1_D1_P: J103.6, U107.JP2_23 (MIPI_CSI_RX0_D1P)
/CAM1_D2_N: J103.11, U107.JP2_33 (MIPI_CSI_RX0_D2N)
/CAM1_D2_P: J103.12, U107.JP2_35 (MIPI_CSI_RX0_D2P)
/CAM1_D3_N: J103.14, U107.JP2_39 (MIPI_CSI_RX0_D3N)
/CAM1_D3_P: J103.15, U107.JP2_41 (MIPI_CSI_RX0_D3P)
/CAM1_SCL: J103.18, U107.JP1_80 (I2C1_SCL_M0)
/CAM1_SDA: J103.17, U107.JP1_82 (I2C1_SDA_M0)
/DISP_5: J108.5, U107.JP1_41 (GPIO4_A4)
/DISP_6: J108.6, U107.JP1_45 (GPIO4_A1)
/DISP_7: J108.7, U107.JP1_47 (GPIO4_A3)
/DISP_SCL: J108.3, U107.JP1_24 (GPIO3_D3)
/DISP_SDA: J108.4, U107.JP1_34 (GPIO4_A5)
/ENC2_A: R115.1, SW102.A, U107.JP1_46 (GPIO4_A2)
/ENC2_B: R116.1, SW102.B, U107.JP1_48 (GPIO4_A0)
/ENC_A: R107.1, SW101.A, U107.JP1_28 (GPIO3_D7)
/ENC_B: R114.1, SW101.B, U107.JP1_30 (GPIO3_D4)
/GPIO_LEDring: J104.1, U107.JP1_31 (GPIO4_C0); also elsewhere on the board
/GPIO_MENU: SW102.S1, U107.JP1_54 (GPIO4_C3)
/GPIO_SHUTTER: SW101.S1, U107.JP1_29 (GPIO3_D5)
/Pi_SPI_CLK: J107.5 (CLK), U107.JP1_57 (SDMMC0_CLK)
/Pi_SPI_CS: J107.2 (DAT3/CD), U107.JP1_61 (SDMMC0_D3)
/Pi_SPI_MISO: J107.7 (DAT0), U107.JP1_63 (SDMMC0_D0)
/Pi_SPI_MOSI: J107.3 (CMD), U107.JP1_62 (SDMMC0_CMD)
GND: C105.2, J101.A1 (GND), J101.A12 (GND), J101.B1 (GND), J101.B12 (GND), J101.S1 (SHIELD), J102.2, J103.1, J103.4, J103.7, J103.10, J103.13, J103.16, J103.22, J104.3, J107.6 (VSS), J107.9 (SHIELD), J108.8, R101.1, R102.2, R104.2, SW101.C, SW101.S2, SW102.C, SW102.S2, U101.3 (GND), U102.2 (GND), U107.JP1_1 (GND_JP1_1); also elsewhere on the board
unnamed: J102.1, U101.5 (BAT)
unnamed: R101.2, U101.2 (PROG)
unnamed: R102.1, U101.1 (TEMP)
unnamed: R103.1, R104.1, U102.3 (FB)

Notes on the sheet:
cam1
power

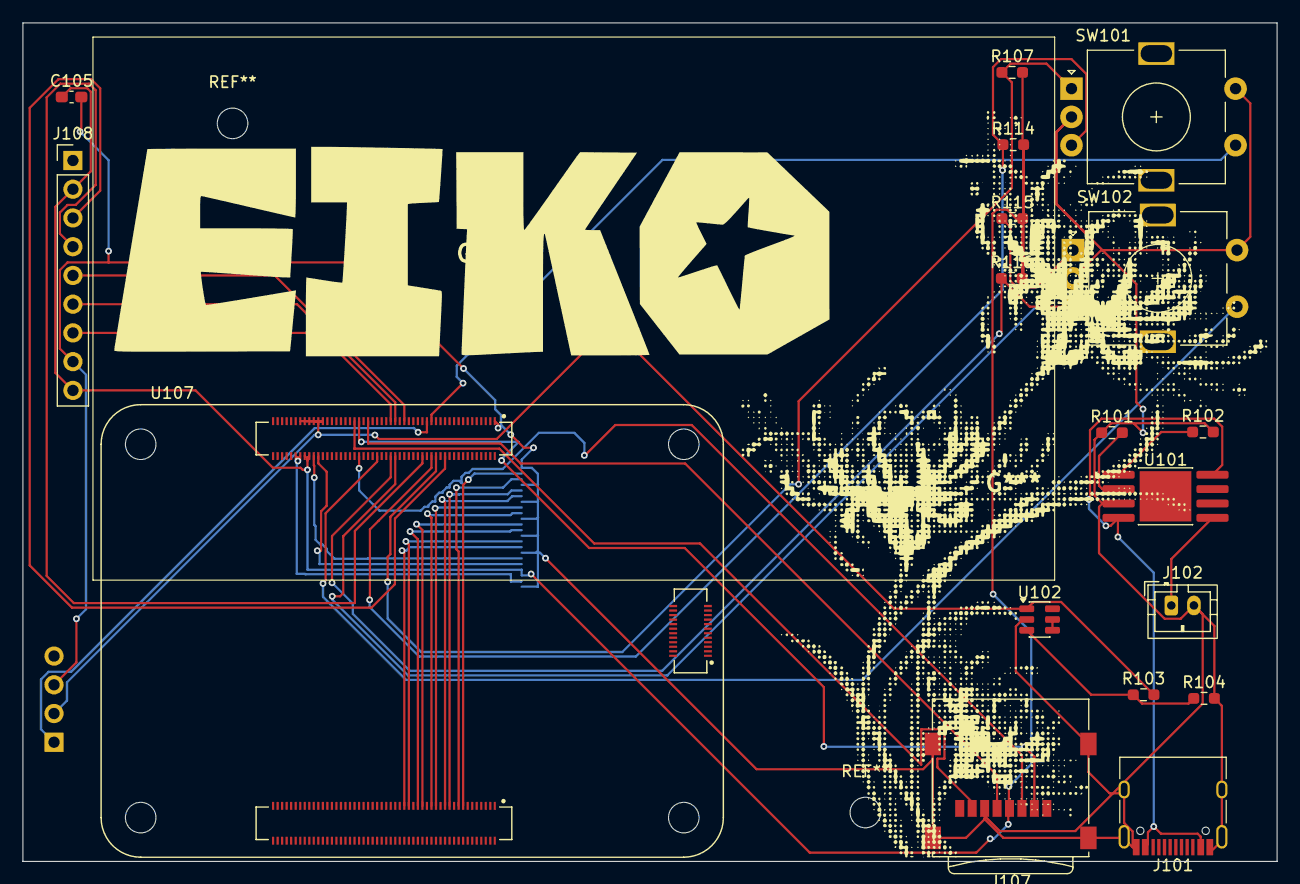
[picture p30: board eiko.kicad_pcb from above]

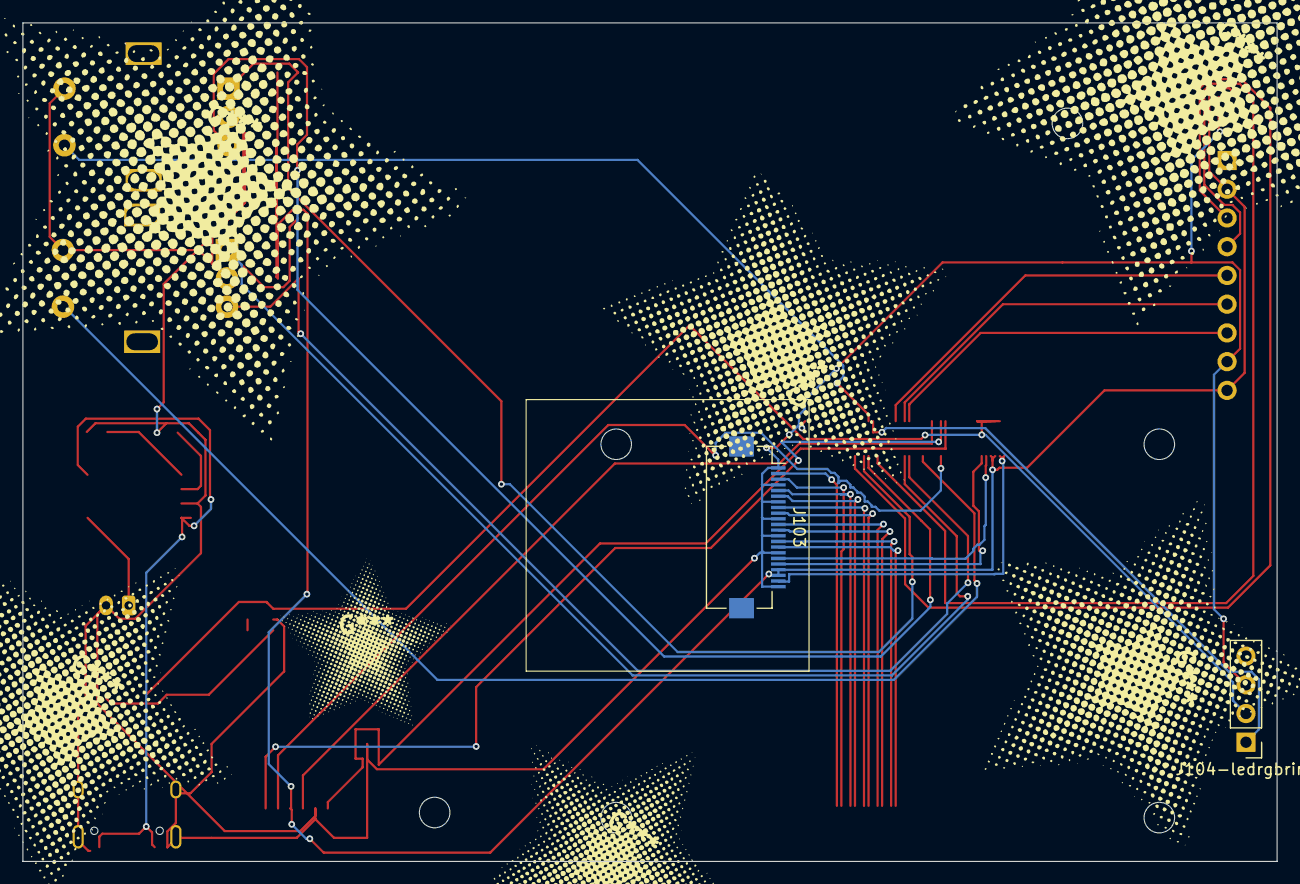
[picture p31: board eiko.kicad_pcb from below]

Board: 2 copper layers, 110.8 x 74.1 mm, 20 parts (2 on the bottom side), 38 nets.

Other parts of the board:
J104-ledrgbring: Conn_01x04; PinHeader_1x04_P2.54mm_Vertical

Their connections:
+5V_BOOST: J104-ledrgbring.2; also elsewhere on the board
/GPIO_LEDring: J104-ledrgbring.1; also elsewhere on the board
GND: J104-ledrgbring.3; also elsewhere on the board

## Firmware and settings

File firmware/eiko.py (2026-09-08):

import os
import time
from datetime import datetime
from PIL import Image
import RPi.GPIO as GPIO
from picamera2 import Picamera2
from rpi_ws281x import PixelStrip, Color
import ST7789

SHUTTER = 125
ENCA    = 127
ENCB    = 124
ENC2A   = 128
ENC2B   = 130
ENC2BTN = 147

TFTDC  = 132
TFTRST = 131
TFTBL  = 129
TFTCS  = 0

LEDPIN   = 144
LEDCOUNT = 24

PICS = "/home/orangepi/Pictures"
os.makedirs(PICS, exist_ok=True)

COLORS = [
    Color(255, 255, 255),
    Color(255, 0,   0),
    Color(0,   255, 0),
    Color(0,   0,   255),
    Color(0,   255, 255),
    Color(148, 0,   211),
    Color(255, 100, 0),
    Color(0,   0,   0),
]

GPIO.setmode(GPIO.BCM)
GPIO.setwarnings(False)
for p in [SHUTTER, ENCA, ENCB, ENC2A, ENC2B, ENC2BTN]:
    GPIO.setup(p, GPIO.IN, pull_up_down=GPIO.PUD_UP)

strip = PixelStrip(LEDCOUNT, LEDPIN, 800000, 10, False, 128, 0)
strip.begin()

def setled(c):
    for i in range(strip.numPixels()):
        strip.setPixelColor(i, c)
    strip.show()

setled(Color(0, 0, 0))

cam = Picamera2()
cam.configure(cam.create_preview_configuration(main={"size": (240, 320), "format": "RGB888"}))
cap = cam.create_still_configuration(main={"size": (3280, 2464)})
cam.start()
time.sleep(1)

disp = ST7789.ST7789(height=320, width=240, rotation=90, port=0,
                     cs=TFTCS, dc=TFTDC, rst=TFTRST, backlight=TFTBL,
                     spi_speed_hz=80000000)

cidx   = 0
ledon  = False
elast  = GPIO.input(ENCA)
e2last = GPIO.input(ENC2A)

def shoot(ch):
    time.sleep(0.05)
    if GPIO.input(SHUTTER) == GPIO.LOW:
        fname = os.path.join(PICS, f"eiko_{datetime.now().strftime('%Y%m%d_%H%M%S')}.jpg")
        cam.switch_mode_and_capture_file(cap, fname)
        if ledon:
            setled(Color(255, 255, 255))
            time.sleep(0.08)
            setled(COLORS[cidx])

def toggle(ch):
    global ledon
    time.sleep(0.05)
    if GPIO.input(ENC2BTN) == GPIO.LOW:
        ledon = not ledon
        setled(COLORS[cidx] if ledon else Color(0, 0, 0))

def enc2(ch):
    global cidx, e2last
    a = GPIO.input(ENC2A)
    if a != e2last:
        cidx = (cidx + (1 if GPIO.input(ENC2B) != a else -1)) % len(COLORS)
        if ledon:
            setled(COLORS[cidx])
        e2last = a

GPIO.add_event_detect(SHUTTER, GPIO.FALLING, callback=shoot,  bouncetime=200)
GPIO.add_event_detect(ENC2BTN, GPIO.FALLING, callback=toggle, bouncetime=200)
GPIO.add_event_detect(ENC2A,   GPIO.BOTH,    callback=enc2)

try:
    while True:
        frame = cam.capture_array()
        disp.display(Image.fromarray(frame).resize((240, 320)))
        time.sleep(0.033)
except KeyboardInterrupt:
    pass
finally:
    cam.stop()
    setled(Color(0, 0, 0))
    GPIO.cleanup()

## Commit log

2026-09-07 add BOM.csv
    [BOM.csv]
2026-09-08 add cad/pcb files, lapse links, update readme
    [eiko-B_Cu.gbr, eiko-B_Mask.gbr, eiko-B_Paste.gbr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]
